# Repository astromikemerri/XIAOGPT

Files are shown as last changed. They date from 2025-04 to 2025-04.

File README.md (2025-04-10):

# XIAOGPT
This is a miniaturized version of my <A href=https://github.com/astromikemerri/ESPGPT>ESPGPT project</a>, designed to see quite how small a box I could fit it in.  I also added in voice cloning using the ElevenLabs API, and a RAG layer with biographical facts to inform the ChatGPT responses, to create a digital mini-me, or mini-you if you would like to build your own!

To make things as tiny as possible, I have switched to an even smaller microcontroller (with the added benefit of built-in battery management for a stand-alone device), removed the push-button-to-speak by using simple voice activation instead, done away with the SD card for storing audio files by using a SPIFFS file system for storage in microcontroller memory, used a smaller speaker, and replaced the separate LED status indicator with the on-board LED.

So, the hardware required for this stripped-down version is just:
<ul>
  <li> Seeed Studio XIAO ESP32S3 microcontroller</li>
  <li> INMP441 I2S microphone</li>
  <li> Max98357 I2S audio amplifier breakout board</li>
  <li> 3W 8 ohm speaker</li>
  <li> (and a suitable rechargeable battery like a 3.7V 300mAh 602030 Li-Po and an on-off switch if you want to create a stand-alone device) </li>
</ul>
This should all <b>just</b> <A href=XIAOGPTfritzing.jpg>fit on a mini breadboard</A> (here's <A href=XIAOGPT.fzz>the Fritzing file</A>), and end up <A href=XIAOGPTimage.jpeg>looking something like this</A> (with a 10p for scale):

<p>
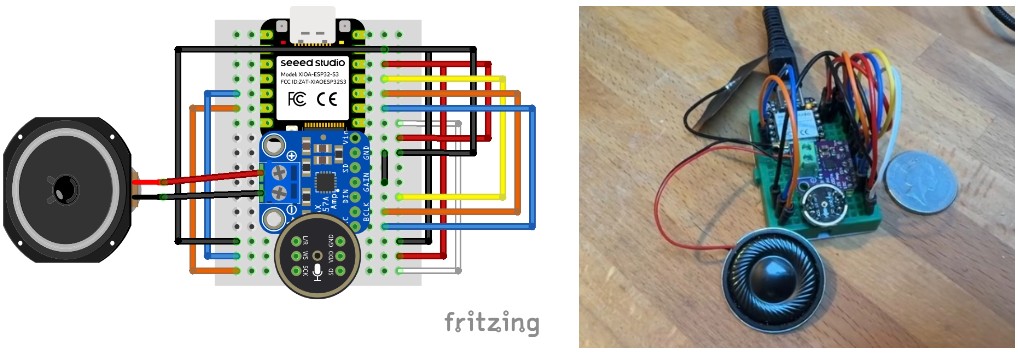
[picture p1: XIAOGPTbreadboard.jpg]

</p>
<A HREF=XIAOGPTdist.ino>The code to make all of this work</a> calls APIs from both OpenAI (for speech-to-text and ChatGPT) and ElevenLabs (with whom I generated a clone of my voice for the text-to-speech implementation, so I could get the gizmo to pretend to be me).  If you want to keep things simpler and don't want to use a voice clone, check out the code for the <A href=https://github.com/astromikemerri/ESPGPT>original project</a>, which just uses the generic OpenAI TTS, so no need to sign up with ElevenLabs. Note that to use these APIs, you need access to both OpenAI and ElevenLabs, <b>WHICH MAY COST MONEY</b>.  Information on the cost of these services is available for both <A href=https://openai.com/api/pricing/>OpenAI</a> and <a href=https://elevenlabs.io/pricing>ElevenLabs</a>.

Since my ambition here was to try and make this gizmo pretend to be me, I also added in a simple RAG (retrieval-augmented generation) layer to the call to ChatGPT, which searches a biographical database for keywords in each prompt, and prepends any biographical information retrieved to the ChatGPT call.  The database is a text file called "bio.txt" that you upload to the SPIFFS file system before running the main code.  The file format is just a series of lines comprising the keywords you want to check for and the associated biographical facts, separated by a colon, so you can populate the file with as much biographical information as you require like this:

```
birthplace, born: you were born in Milton Keynes in 1875.
food: you eat pretty much anything except porridge.  You particularly like oranges.
job, work, employment: You worked for your entire career as an accountant in a large firm.  You are now retired.
current project, experiment, ESP32, AI, ChatGPT: You are working on a voice-activated ChatGPT interface using an ESP32.
hobbies, pastimes, fantasies, fantasy: you enjoy stamp collecting, and making up entirely fictional autobiographical facts.
```

Depending on which IDE you are using, there may be no straightforward way to upload this file to SPIFFS.  <A href=UploadBio.ino>Here</a> is a sketch that exploits the ESP32's ability to host a web server, as a simple way to do so.  Upload this sketch to the ESP32, connect your PC's WiFi to ESP32_AP (password 12345678), open a web browser to 192.168.4.1, select and upload the file called "bio.txt", and then you can install <A HREF=XIAOGPTdist.ino>the main XIAOGPT sketch</A>.

Once all this is done, the gizmo should work <A HREF=XIAOGPT.mov>something like this</a>. 

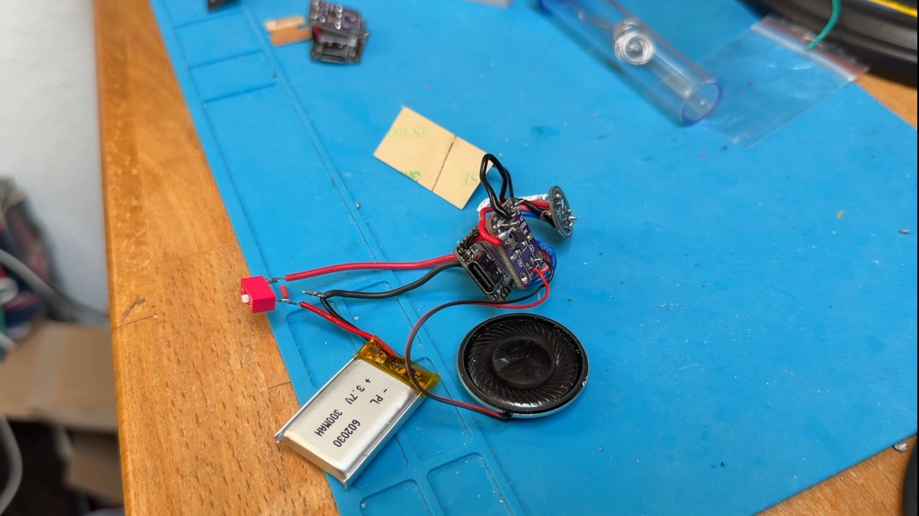
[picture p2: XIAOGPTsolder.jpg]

And, just to finish the project off, I soldered together the components rather than using a breadboard, attached a battery and on/off switch to the pads on the back of the XIAO ESP32S3, and squeezed the whole thing into a tiny box.  You can listen in on a slightly longer chat that I had with this stand-alone boxed version of myself <A HREF=https://youtu.be/_BVf_5BmFiE>here on YouTube</A>.
<BR><P></P>
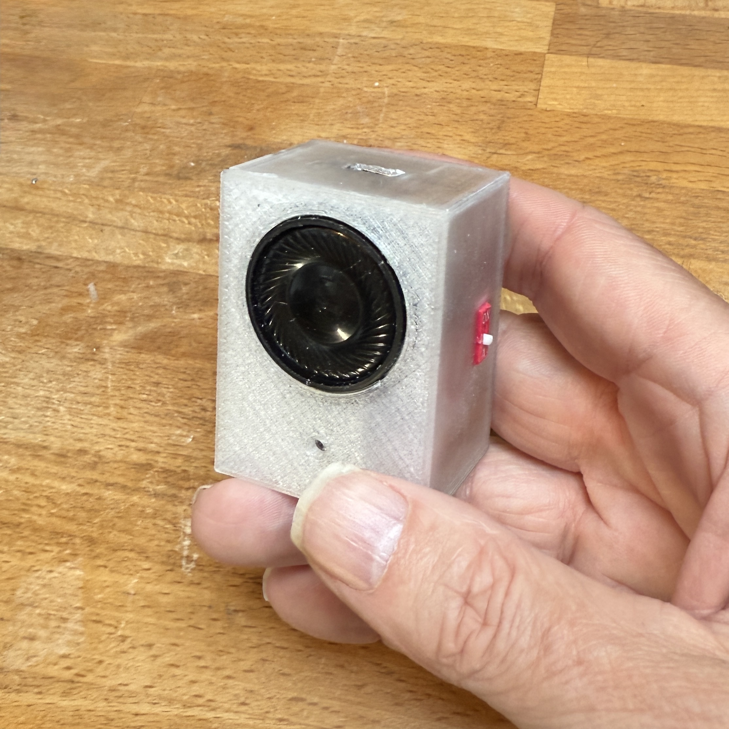
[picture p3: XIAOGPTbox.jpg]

It is worth noting that, in addition to providing the engine that makes this gizmo work, ChatGPT was also responsible for coming up with many of the ideas (like using a RAG layer to provide biographical details, and how to upload the biographical database file to SPIFFS), producing most of the code (which is why it is functional rather than beautiful!), and even for generating <A href=XIAOGPT.stl>the CAD  model</a> from which I 3D printed the box to put the final version inside.

It is an indication of what someone with even my limited technical skills can achieve with the assistance of an LLM!

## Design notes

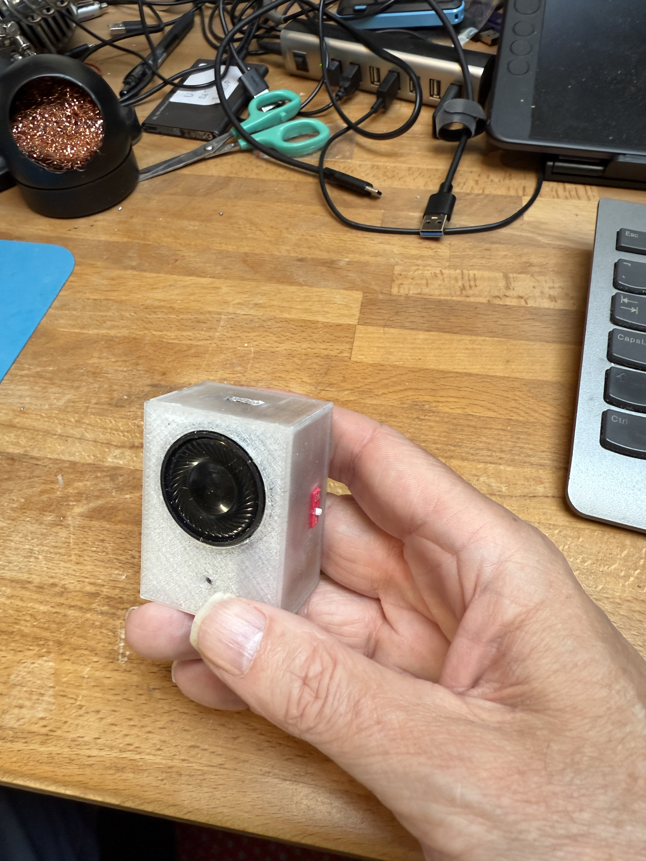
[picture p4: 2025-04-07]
XIAOGPTbox.jpeg

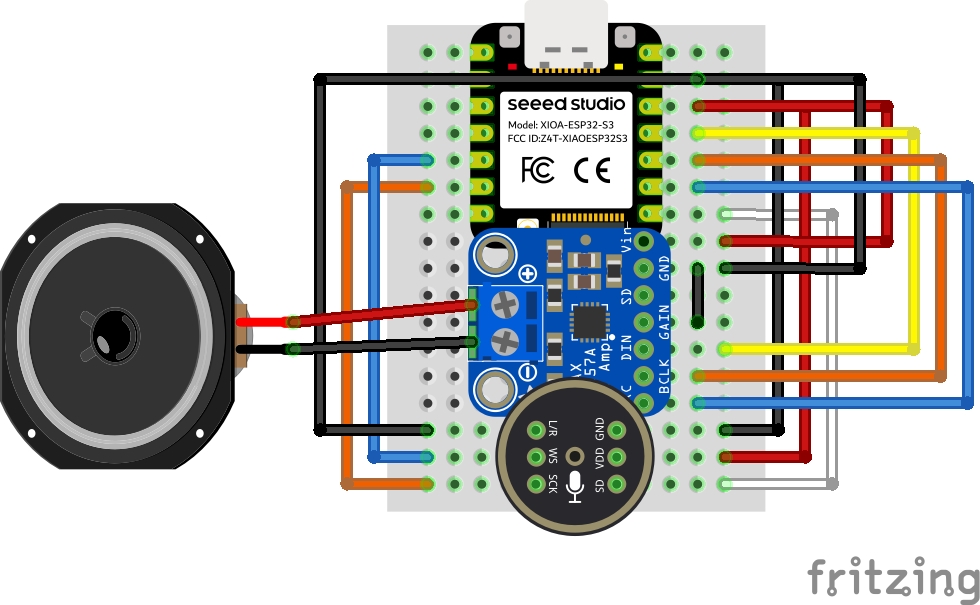
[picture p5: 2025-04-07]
XIAOGPTfritzing.jpg

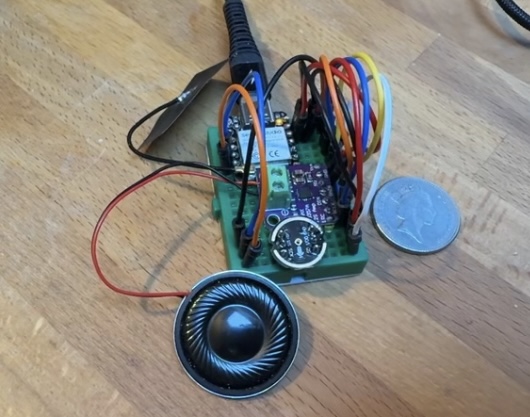
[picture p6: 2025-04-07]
XIAOGPTimage.jpeg

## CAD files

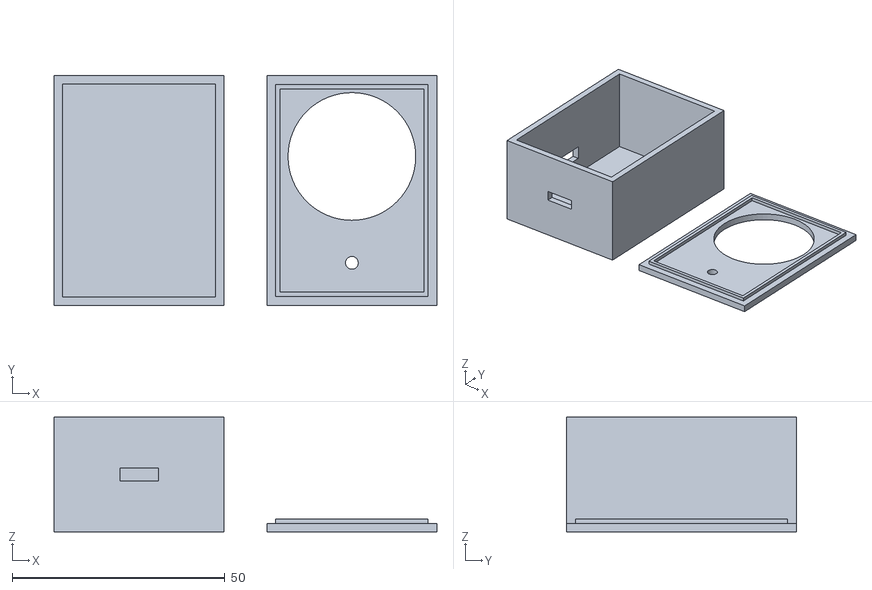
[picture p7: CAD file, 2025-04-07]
XIAOGPT.stl
90.0 x 54.0 x 27.0

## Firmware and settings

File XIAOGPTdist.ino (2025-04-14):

// Code to implement a voice-acitvated interface to ChatGPT, 
// using ElevenLabs voice cloning and a biographical RAG layer to make the device pretend to be you!

#include <Arduino.h>
#include <driver/i2s.h>
#include <SPIFFS.h>
#include <string.h>
#include <ctype.h>

#include <WiFi.h>
#include <WiFiClientSecure.h>
#include <HTTPClient.h>
#include <ArduinoJson.h>

// File path for biography database
const char *bioFilePath = "/bio.txt";  // Use "/bio.json" if using JSON


// -----------------------------------------------------------------------------
// Wi-Fi, OpenAI and ElevenLabs credentials
// -----------------------------------------------------------------------------

// You need to edit these four lines with your own credentials
#define WIFI_SSID     "YOUR WIFI SSID"
#define WIFI_PASSWORD "YOUR WIFI PASSWORD"
const char* openai_api_key  = "YOUR OPENAI API KEY";
const char* elevenlabs_api_key  = "YOUR ELEVENLABS API KEY";
const char* voiceID = "YOUR CLONED ELEVENLABS VOICE ID";

const char* openai_endpoint = "https://api.openai.com/v1/chat/completions";
const char* serverName      = "https://api.openai.com/v1/audio/speech";



// -----------------------------------------------------------------------------
// Global conversation / ChatGPT info
// -----------------------------------------------------------------------------
const int NCONV = 10; // Number of conversation parts to remember
String conversationHistory[NCONV];
int historyIndex = 0;


// REPLACE WITH A BRIEF DESCRIPTION OF YOURSELF, AND HOW YOU WANT CHATGPT TO BEHAVE. SOMETHING LIKE:
const char *characterCharacteristics = 
  "You are Fred Bloggs, a retired accountant." 
  "Provide fairly short helpful answers in a conversational tone.  You always respond explicitly to questions asked."
  "you do not repeat previous answers, but come up with something different to say. You do not make up biographical facts."
  "You are working over an audio link, so your responses are optimised for being heard rather than read."
  "You always use British English vocabulary and measurements.";

// Various models you can use here
const char *GPTModel = "gpt-3.5-turbo";
// Playing with this parameter alters how random ChatGPT's responses are
const float temperature = 0.35;

WiFiClientSecure client;
HTTPClient http;

// Amplifier pin definitions
#define I2S_SPK_PORT I2S_NUM_0
#define I2S_SPEAKER_BCLK  GPIO_NUM_8
#define I2S_SPEAKER_LRC   GPIO_NUM_7
#define I2S_SPEAKER_DIN   GPIO_NUM_9

// Microphone pin definitions
#define I2S_MIC_PORT I2S_NUM_1
#define I2S_MIC_BCLK  GPIO_NUM_6
#define I2S_MIC_LRC   GPIO_NUM_5
#define I2S_MIC_DOUT  GPIO_NUM_44

#define WAV_HEADER_SIZE 44
#define SAMPLE_RATE 16000
#define BUFFER_SIZE 1024
#define AMPLIFY_FACTOR 64
#define QUERYFILENAME "/question.wav"
#define RESPONSEFILENAME "/answer.pcm"

#define START_THRESHOLD 50
#define STOP_THRESHOLD 40
#define SILENCE_DURATION 2000
#define BASELINE_SMOOTHING_FACTOR 0.97f
#define BYTES_PER_SAMPLE 2
#define USER_LED_PIN 21
#define MIC_WARMUP_READS 100

float baselineVolume;

unsigned long silenceStartTime = 0;
bool recording = false;
File file;
uint32_t totalBytes = 0;
unsigned long lastPrintTime = 0;
bool speakerInstalled = false;
bool wifiOn = false;

// -----------------------------------------------------------------------------
// connectToWiFi()
// -----------------------------------------------------------------------------
void connectToWiFi() {
  WiFi.begin(WIFI_SSID, WIFI_PASSWORD);
  Serial.print("Connecting to Wi-Fi");
  while (WiFi.status() != WL_CONNECTED) {
    delay(800);
    Serial.print(".");
    flashLED(1);
  }
  Serial.println("\nConnected to Wi-Fi.");
  wifiOn = true;
  client.setInsecure();
  http.setTimeout(15000);
}

// And switch it off when not needed to save power/heat
void disableWiFi(){
  WiFi.disconnect();
  WiFi.mode(WIFI_OFF);
  Serial.println("WiFi switched off");
  wifiOn = false;
}


// -----------------------------------------------------------------------------
// flashLED()
// -----------------------------------------------------------------------------
void flashLED(int nflash){
  for(int i=0; i<nflash; i++){
    digitalWrite(USER_LED_PIN, LOW);
    delay(100);
    digitalWrite(USER_LED_PIN, HIGH);
    delay(100);
  }
}

void setupMicrophone() {
  i2s_driver_uninstall(I2S_MIC_PORT);
  delay(100);

  i2s_config_t mic_config = {
    .mode = (i2s_mode_t)(I2S_MODE_MASTER | I2S_MODE_RX),
    .sample_rate = SAMPLE_RATE,
    .bits_per_sample = I2S_BITS_PER_SAMPLE_16BIT,
    .channel_format = I2S_CHANNEL_FMT_ONLY_LEFT,
    .communication_format = I2S_COMM_FORMAT_I2S_MSB,
    .intr_alloc_flags = ESP_INTR_FLAG_LEVEL1,
    .dma_buf_count = 8,
    .dma_buf_len = BUFFER_SIZE,
    .use_apll = 0,
    .tx_desc_auto_clear = false,
    .fixed_mclk = 0
  };

  i2s_pin_config_t mic_pin_config = {
    .bck_io_num = I2S_MIC_BCLK,
    .ws_io_num = I2S_MIC_LRC,
    .data_out_num = I2S_PIN_NO_CHANGE,
    .data_in_num = I2S_MIC_DOUT
  };

  i2s_driver_install(I2S_MIC_PORT, &mic_config, 0, NULL);
  i2s_set_pin(I2S_MIC_PORT, &mic_pin_config);
  i2s_set_clk(I2S_MIC_PORT, SAMPLE_RATE, I2S_BITS_PER_SAMPLE_16BIT, I2S_CHANNEL_MONO);
  Serial.println("Microphone I2S Configured.");

  // Discard initial noisy reads
  int16_t discardBuf[BUFFER_SIZE];
  size_t bytesRead;
  for (int i = 0; i < MIC_WARMUP_READS; i++) {
    i2s_read(I2S_MIC_PORT, discardBuf, sizeof(discardBuf), &bytesRead, 10);
  }
  Serial.println("Microphone warmup done.");
}

void setupSpeaker() {
  if (speakerInstalled) {
    i2s_driver_uninstall(I2S_SPK_PORT);
    delay(100);
    speakerInstalled = false;
  }

  i2s_config_t i2s_config = {
    .mode = (i2s_mode_t)(I2S_MODE_MASTER | I2S_MODE_TX),
    .sample_rate = SAMPLE_RATE,
    .bits_per_sample = I2S_BITS_PER_SAMPLE_16BIT,
    .channel_format = I2S_CHANNEL_FMT_ONLY_LEFT,
    .communication_format = I2S_COMM_FORMAT_I2S_MSB,
    .intr_alloc_flags = ESP_INTR_FLAG_LEVEL1,
    .dma_buf_count = 8,
    .dma_buf_len = BUFFER_SIZE,
    .use_apll = 0,
    .tx_desc_auto_clear = true,
    .fixed_mclk = 0
  };

  i2s_pin_config_t pin_config = {
    .bck_io_num = I2S_SPEAKER_BCLK,
    .ws_io_num = I2S_SPEAKER_LRC,
    .data_out_num = I2S_SPEAKER_DIN,
    .data_in_num = I2S_PIN_NO_CHANGE
  };

  i2s_driver_install(I2S_SPK_PORT, &i2s_config, 0, NULL);
  i2s_set_pin(I2S_SPK_PORT, &pin_config);
  i2s_set_clk(I2S_SPK_PORT, SAMPLE_RATE, I2S_BITS_PER_SAMPLE_16BIT, I2S_CHANNEL_MONO);
  speakerInstalled = true;
  Serial.println("Speaker I2S Configured.");
}

void writeWAVHeader(File file, uint32_t dataSize) {
  uint32_t fileSize = 36 + dataSize;
  uint16_t audioFormat = 1;
  uint16_t numChannels = 1;
  uint16_t bitsPerSample = 16;
  uint32_t byteRate = SAMPLE_RATE * numChannels * bitsPerSample / 8;
  uint16_t blockAlign = numChannels * bitsPerSample / 8;
  uint32_t sampleRate = SAMPLE_RATE;

  file.seek(0);
  file.write((const uint8_t*)"RIFF", 4);
  file.write((uint8_t*)&fileSize, 4);
  file.write((const uint8_t*)"WAVE", 4);
  file.write((const uint8_t*)"fmt ", 4);
  uint32_t subchunk1Size = 16;
  file.write((uint8_t*)&subchunk1Size, 4);
  file.write((uint8_t*)&audioFormat, 2);
  file.write((uint8_t*)&numChannels, 2);
  file.write((uint8_t*)&sampleRate, 4);
  file.write((uint8_t*)&byteRate, 4);
  file.write((uint8_t*)&blockAlign, 2);
  file.write((uint8_t*)&bitsPerSample, 2);
  file.write((const uint8_t*)"data", 4);
  file.write((uint8_t*)&dataSize, 4);
}

void startRecording() {
  digitalWrite(USER_LED_PIN, HIGH);
  file = SPIFFS.open(QUERYFILENAME, "w+");
  for (int i = 0; i < 44; i++) file.write((uint8_t)0);
  totalBytes = 0;
  recording = true;
  silenceStartTime = millis();
  Serial.println("Started recording.");
}

void stopRecording() {
  writeWAVHeader(file, totalBytes);
  file.close();
  recording = false;
  Serial.println("Stopped recording.");
}


// -----------------------------------------------------------------------------
// Modified microphone check: Reads from the microphone and either (a) updates baseline
// if not recording, and if threshold is exceeded, starts recording and writes the triggering buffer,
// or (b) while recording, appends data and stops when enough silence is detected.
// -----------------------------------------------------------------------------
void checkMicrophoneAndRecord() {
    int16_t buffer[BUFFER_SIZE];
    size_t bytesRead = 0;
    int32_t sum = 0;

    esp_err_t result = i2s_read(I2S_MIC_PORT, buffer, sizeof(buffer), &bytesRead, 10);
    if (result != ESP_OK || bytesRead == 0) return;

    int samples = bytesRead / BYTES_PER_SAMPLE;
    if (samples == 0) return;

    for (int i = 0; i < samples; i++) {
        sum += abs(buffer[i]);
    }
    int average = sum / samples;

    if (!recording) {
        // Update baseline when the sound is below the trigger threshold.
        if (average < (START_THRESHOLD + baselineVolume)) {
            baselineVolume = (baselineVolume * BASELINE_SMOOTHING_FACTOR) +
                             (average * (1.0f - BASELINE_SMOOTHING_FACTOR));
        }
        // If the sound goes above the trigger level then start recording and
        // immediately write the current (triggering) buffer.
        if (average > (START_THRESHOLD + baselineVolume)) {
            startRecording();
            file.write((uint8_t*)buffer, bytesRead);
            totalBytes += bytesRead;
            Serial.println("Sound threshold exceeded: triggering pre-buffer saved.");
        }
    } else { // recording is true
        // Append the current buffer to the recording.
        file.write((uint8_t*)buffer, bytesRead);
        totalBytes += bytesRead;

        // Check for silence. If the average falls below the (stop) threshold we start
        // a timer, and if the silence lasts long enough, we end the recording.
        if (average < (STOP_THRESHOLD + baselineVolume)) {
            if (silenceStartTime == 0) {
                silenceStartTime = millis();
            } else if (millis() - silenceStartTime > SILENCE_DURATION) {
                stopRecording();
            }
        } else {
            silenceStartTime = 0;
        }
    }
}

void playAudioFile(const char* filename, float amplification) {
  // Determine the file extension
  const char* ext = strrchr(filename, '.');
  if (!ext) {
    Serial.println("Error: File extension not found!");
    return;
  }
  
  // Check file extension (case-insensitive)
  bool isWav = (strcasecmp(ext, ".wav") == 0);
  bool isPcm = (strcasecmp(ext, ".pcm") == 0);
  
  if (!isWav && !isPcm) {
    Serial.println("Error: Unsupported file extension!");
    return;
  }
  
  setupSpeaker();
  File playFile = SPIFFS.open(filename, "r");
  if (!playFile) {
    Serial.println("Error opening file!");
    return;
  }
  
  // Skip the WAV header if the file is a .wav file
  if (isWav) {
    playFile.seek(44);
  }
  
  int16_t buffer[BUFFER_SIZE];
  size_t bytesRead;
  while ((bytesRead = playFile.read((uint8_t*)buffer, sizeof(buffer))) > 0) {
    int sampleCount = bytesRead / sizeof(int16_t);
    // Apply amplification with clipping
    for (int i = 0; i < sampleCount; i++) {
      float amplifiedSample = (float)buffer[i] * amplification;
      if (amplifiedSample > 32767.0f) {
        amplifiedSample = 32767.0f;
      } else if (amplifiedSample < -32768.0f) {
        amplifiedSample = -32768.0f;
      }
      buffer[i] = (int16_t)amplifiedSample;
    }
    size_t bytesWritten;
    i2s_write(I2S_SPK_PORT, buffer, bytesRead, &bytesWritten, portMAX_DELAY);
  }
  
  playFile.close();
}

void measureAmbientNoise() {
  Serial.println("Measuring ambient noise...");
  setupMicrophone(); // sets up I2S & discards 100 reads

  // let mic settle ~2s
  delay(2000);

  unsigned long startTime     = millis();
  const unsigned long measureDuration = 1000; // 1s
  std::vector<long> volumes;

 
  while ((millis() - startTime) < measureDuration) {
    int16_t buffer[256];
    size_t bytesRead = 0;
    if (i2s_read(I2S_MIC_PORT, buffer, sizeof(buffer), &bytesRead, 100) == ESP_OK) {
      size_t samplesRead = bytesRead / sizeof(int16_t);
      if (samplesRead > 0) {
        long sumAbs = 0;
        for (size_t i = 0; i < samplesRead; i++) {
          sumAbs += abs(buffer[i]);
        }
        long avgVolume = sumAbs / samplesRead;
        volumes.push_back(avgVolume);
      }
    }
  }


  if(volumes.empty()){
    baselineVolume    = 0;
    Serial.println("No data => ");
    return;
  }

  long total = 0;
  for(auto v : volumes){
    total += v;
  }
  baselineVolume = float(total) / float(volumes.size());
  Serial.print("Ambient noise measurement complete: baseline=");
  Serial.println(baselineVolume);
  
}



// -----------------------------------------------------------------------------
// STTOpenAIAPI()
// -----------------------------------------------------------------------------
String STTOpenAIAPI(const char* filePath){
  if(WiFi.status()!=WL_CONNECTED){
    Serial.println("Wi-Fi not connected!");
    return "";
  }

  File wavFile=SPIFFS.open(filePath);
  if(!wavFile){
    Serial.println("Error: Failed to open WAV file.");
    return "";
  }
  size_t fileSize=wavFile.size();
  if(fileSize==0){
    Serial.println("Error: WAV file is empty.");
    wavFile.close();
    return "";
  }

  WiFiClientSecure sttClient;
  sttClient.setInsecure();
  if(!sttClient.connect("api.openai.com", 443)){
    Serial.println("Error: Connection to OpenAI STT failed.");
    wavFile.close();
    return "";
  }

  String boundary="----ESP32Boundary";
  sttClient.print("POST /v1/audio/transcriptions HTTP/1.1\r\n");
  sttClient.print("Host: api.openai.com\r\n");
  sttClient.print("Authorization: Bearer "+String(openai_api_key)+"\r\n");
  sttClient.print("Content-Type: multipart/form-data; boundary="+boundary+"\r\n");

  String modelPart= "--"+boundary+"\r\n"
                    "Content-Disposition: form-data; name=\"model\"\r\n\r\n"
                    "whisper-1\r\n";
  String filePartStart= "--"+boundary+"\r\n"
                        "Content-Disposition: form-data; name=\"file\"; filename=\"question.wav\"\r\n"
                        "Content-Type: audio/wav\r\n\r\n";
  String filePartEnd= "\r\n--"+boundary+"--\r\n";

  size_t contentLength=modelPart.length()+filePartStart.length()+fileSize+filePartEnd.length();
  sttClient.print("Content-Length: "+String(contentLength)+"\r\n\r\n");

  // send body
  sttClient.print(modelPart);
  sttClient.print(filePartStart);

  const size_t chunkSize=1024;
  uint8_t tempBuf[chunkSize];
  while(wavFile.available()){
    size_t rd=wavFile.read(tempBuf, chunkSize);
    sttClient.write(tempBuf, rd);
  }
  wavFile.close();
  sttClient.print(filePartEnd);

  // read headers
  while(sttClient.connected()){
    String line=sttClient.readStringUntil('\n');
    if(line=="\r") break;
  }

  // read body
  String response;
  while(sttClient.available()){
    response+=(char)sttClient.read();
  }

  DynamicJsonDocument doc(8192);
  DeserializationError error=deserializeJson(doc, response);
  if(error){
    Serial.print("JSON parsing error: ");
    Serial.println(error.c_str());
    return "";
  }

  if(doc["error"].is<JsonObject>()){
    String errMsg=doc["error"]["message"].as<String>();
    Serial.print("OpenAI Whisper error: ");
    Serial.println(errMsg);
    return "";
  }

  if(doc["text"].isNull()){
    Serial.println("STT API returned null or empty text.");
    return "";
  }

  String text=doc["text"].as<String>();
  return tidyStringForJSON(text);
}


/**
 * Helper to remove basic punctuation (e.g. . , ! ?) and lowercase the string.
 * Adjust for any additional punctuation or special characters you need to strip.
 */
String normalizeString(const String& input) {
    String result;
    for (unsigned int i = 0; i < input.length(); i++) {
        char c = input.charAt(i);
        // Keep letters, digits, space; skip punctuation
        if (isalnum(c) || isSpace(c)) {
            result += (char)tolower(c);
        }
        // else skip punctuation characters like '.' ',' '!' '?', etc.
    }
    return result;
}

String findRelevantBioFacts(String userInput) {
    File file = SPIFFS.open(bioFilePath);
    if (!file) {
        Serial.println("Error opening bio file");
        return "";
    }

    // First, normalize the entire user input once
    String normalizedUserInput = normalizeString(userInput);

    String bioFacts = "";
    while (file.available()) {
        String line = file.readStringUntil('\n');
        line.trim();

        int colonIndex = line.indexOf(":");
        if (colonIndex > 0) {
            String keywords = line.substring(0, colonIndex);
            String fact = line.substring(colonIndex + 1);
            fact.trim();

            int keywordStart = 0;
            while (true) {
                int commaIndex = keywords.indexOf(',', keywordStart);
                if (commaIndex == -1) commaIndex = keywords.length();

                String keyword = keywords.substring(keywordStart, commaIndex);
                keyword.trim();

                // Normalize the keyword
                String normalizedKeyword = normalizeString(keyword);

                // Check if the normalized keyword appears in normalized user input
                if (normalizedUserInput.indexOf(normalizedKeyword) != -1 && normalizedKeyword.length() > 0) {
                    bioFacts += fact + " ";
                    break;  // Avoid adding the same fact multiple times
                }

                if (commaIndex == keywords.length()) break;
                keywordStart = commaIndex + 1;
            }
        }
    }
    file.close();
    return bioFacts;
}



// Function to prepend relevant biographical facts to user input
String prependBioToQuery(String userInput) {
    Serial.println("Checking biographical details...");
    String bioFacts = findRelevantBioFacts(userInput);
    if (bioFacts.length() > 0) {
        bioFacts = "Here is some biographical information that overrides any previous knowledge, or anything you might make up: "
                  + bioFacts
                  + "When you answer the question that follows, you can draw on this information, but only if it is relevant."
                  + "You must not quote directly from it, nor must you give any indication that I have just told you these facts. Here is the question: ";
    }
    printFormatted("Bio Facts: " + bioFacts + userInput, 120);
    return bioFacts + userInput;
}
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
void loop() {

// turn off WiFi when not required to reduce power consumption:
  if (wifiOn) {
    disableWiFi();
  }
  // Instead of using the return value, simply read from the microphone which manages the recording state:
  checkMicrophoneAndRecord();

  if (!recording && SPIFFS.exists(QUERYFILENAME)) {

// Useful for debugging microphone and recordings
//    setupSpeaker();
//    playAudioFile(QUERYFILENAME, 32.);

    // Turn on WiFi when needed
    connectToWiFi();

    flashLED(1);
    String transcript = STTOpenAIAPI(QUERYFILENAME);
    Serial.println("Question ------------------------------------------");
    Serial.println(transcript);

    flashLED(2);
  // Add biographical details to try to prevent hallucinations
    String bioPlusTranscript = tidyStringForJSON(prependBioToQuery(transcript));


    flashLED(3);
    String chatResponse = ChatGPTOpenAIAPI(bioPlusTranscript);
    Serial.println("Answer --------------------------------------------");
    printFormatted(chatResponse, 120);
    Serial.println(" ");

    flashLED(4);
    // try stripping all non-basic ASCII, to see if that helps ElevenLabs with its pronunciation
    String cleanChatResponse = stripNonAscii(tidyStringForJSON(chatResponse));
    if(TTSElevenLabsAPI(cleanChatResponse)) {
      playAudioFile(RESPONSEFILENAME, 6.);
    } else {
      Serial.println("Failed to process text.");
    }

    // Blink LED
    flashLED(5);
    SPIFFS.remove(QUERYFILENAME);
    digitalWrite(USER_LED_PIN, LOW);

  }
}

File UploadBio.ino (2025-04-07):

/*
To use this to upload the bio.txt file, upload this sketch and run it.  
Connect PC WIFI to ESP32_AP (password 12345678).  
Open a web browser at 192.168.4.1.
Select and upload file
*/

#include <WiFi.h>
#include "SPIFFS.h"
#include <WebServer.h>

// Create a web server on port 80
WebServer server(80);

// Function to list SPIFFS directory contents (printed to Serial)
void printDirectory(fs::FS &fs, const char * dirname, uint8_t levels) {
  Serial.printf("Listing directory: %s\n", dirname);
  File root = fs.open(dirname);
  if (!root) {
    Serial.println("Failed to open directory");
    return;
  }
  if (!root.isDirectory()) {
    Serial.println("Not a directory");
    return;
  }
  File file = root.openNextFile();
  while (file) {
    if (file.isDirectory()) {
      Serial.print("  DIR : ");
      Serial.println(file.name());
      if (levels) {
        printDirectory(fs, file.name(), levels - 1);
      }
    } else {
      Serial.print("  FILE: ");
      Serial.print(file.name());
      Serial.print("  SIZE: ");
      Serial.println(file.size());
    }
    file = root.openNextFile();
  }
}

// Handler for the root URL: sends an HTML form for file upload
void handleRoot() {
  String html = "<html><head><title>ESP32 File Upload</title></head><body>";
  html += "<h1>Upload a File to SPIFFS</h1>";
  html += "<form method='POST' action='/upload' enctype='multipart/form-data'>";
  html += "<input type='file' name='upload'>";
  html += "<input type='submit' value='Upload'>";
  html += "</form>";
  html += "</body></html>";
  server.send(200, "text/html", html);
}

// This function handles the file upload events
void handleFileUpload() {
  HTTPUpload &upload = server.upload();
  static File file;
  
  if (upload.status == UPLOAD_FILE_START) {
    String filename = "/" + upload.filename;
    Serial.printf("Upload Start: %s\n", filename.c_str());
    // Open file for writing in SPIFFS (overwrite if it exists)
    file = SPIFFS.open(filename, FILE_WRITE);
    if (!file) {
      Serial.println("Failed to open file for writing");
    }
  } 
  else if (upload.status == UPLOAD_FILE_WRITE) {
    // Write received bytes to the file
    if (file)
      file.write(upload.buf, upload.currentSize);
  } 
  else if (upload.status == UPLOAD_FILE_END) {
    if (file) {
      file.close();
      Serial.printf("Upload End: %s, %u bytes\n", upload.filename.c_str(), upload.totalSize);
    }
    // Respond once the file is completely uploaded
    server.send(200, "text/plain", "File Uploaded Successfully");
    // Print updated SPIFFS directory to Serial Monitor
    printDirectory(SPIFFS, "/", 0);
  }
}

void setup() {
  Serial.begin(115200);
  delay(1000);

/*
// Let's try erasing the drive
  Serial.println("Erasing SPIFFS...");
  if (SPIFFS.format()) {
    Serial.println("SPIFFS erased successfully.");
  } else {
    Serial.println("Error erasing SPIFFS.");
  } 
*/

  // Mount SPIFFS (format if mounting fails)
  if (!SPIFFS.begin(true)) {
    Serial.println("SPIFFS Mount Failed");
    return;
  }
  Serial.println("SPIFFS mounted successfully");

  // Set up WiFi in Access Point mode
  const char* ssid = "ESP32_AP";
  const char* password = "12345678";
  WiFi.softAP(ssid, password);
  Serial.print("AP Started. Connect to WiFi network: ");
  Serial.println(ssid);
  Serial.print("AP IP address: ");
  Serial.println(WiFi.softAPIP());

  // Set up web server routes
  server.on("/", HTTP_GET, handleRoot);
  // For file upload, we specify a POST handler and a file-upload callback
  server.on("/upload", HTTP_POST, [](){
    // This lambda is called when the upload is finished (the response is sent in handleFileUpload)
  }, handleFileUpload);

  server.begin();
  Serial.println("HTTP server started");

  // Optionally, list SPIFFS contents at startup
  printDirectory(SPIFFS, "/", 0);
}

void loop() {
  server.handleClient();
}
